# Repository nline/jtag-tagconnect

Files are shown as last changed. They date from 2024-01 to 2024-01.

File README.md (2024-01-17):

JTAG to Tag Connect
===================

This PCB is an adapter that converts the [20 pin JLink](https://www.segger.com/jlink-debug-probes.html) connector to
a [6-pin Tag Connect](http://www.tag-connect.com/TC2030-IDC-NL),
much like [this](https://www.segger.com/jlink-6-pin-adapter.html) board.
Ours, however, additionally contains an onboard LDO
that can supply 3.3V to the attached device and the VTRef pin on the J-Link programmer
so that it can program boards that are not self powered.

This most recent (nLine) version allows you to additionally power the target board with 5V and
also select the whether to keep the I/O at the supply voltage or divide it down from 5V to 3V3. 
This allows powering higher voltage boards while still operating the MCU at 3V3 without on-board
level shifters.

Interface
---------

- **Switch 1**, labeled `VSupply`: Set to 5V to connect teh VCC pin on the TagConnect
header (and the attached board) to the 5VC output from the JLink.
Set to `3V3` to connect the `VCC` pin on the TagConnect
header (and the attached board to be programmed) and the `VTRef` pin from
the Segger JLink to the 3.3 V output from the regulator.
Set to `DEV` to directly connect the `VTRef` pin on the JLink to the TagConnect
VCC pin. This sets the I/O voltage for the JLink, but does not power the target board.

- **Switch 2**, labeled `SWDIO`: This switch can connect the `SWDIO` and
`!RESET` signals, which is needed on some ICs. To leave the signals
disconnected, leave the switch in the empty (down) position.

- **Switch 3** labeled `VIO`: Set to `Supply` to use with I/O voltage same as VSupply. Set to
`5V->3V3` to divide a 5V supply down to 3V3 for 3V3 I/O operation.

Troubleshooting
---------------

1. Blue LED does not come on when attached to JLink.
You need to enable the 5 V output on the JLink:

        $ JlinkExe
        power on perm

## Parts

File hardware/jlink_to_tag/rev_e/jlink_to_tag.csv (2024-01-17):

Qty | Value | Device | Package | Parts | Description | DIGIKEY | MF | MPN | OC_FARNELL | OC_NEWARK | PROD_ID | VALUE
1 |  | ML20 | ML20 | J1 | HARTING | S9172-ND |  |  | unknown | unknown
2 | 0.01uF | C-EUC0603 | C0603 | C1, C2 | CAPACITOR, European symbol | 490-1512-1-ND
1 | 10k | RESISTOR0603_RES | 0603-RES | R2 | Resistor | RMCF0603FT10K0CT-ND
1 | 10uF | CAP_POL1206 | EIA3216 | C3 | Capacitor Polarized | 399-3684-1-ND
1 | 20k | RESISTOR0603_RES | 0603-RES | R3 | Resistor | P20.0KHCT-ND
1 | 470 | RESISTOR0603-RES | 0603-RES | R1 | Resistor | P470DBCT-ND
1 | BLUE | LED-BLUE0603 | LED-0603 | D1 | Blue LEDs for production use | 160-1827-1-ND |  |  |  |  | DIO-08575 | BLUE
1 | EVQP2 | EVQP2 | EVQP2 | S1 | SWITCH TACTILE SPST-NO 0.02A 15V | P11084SCT-ND
1 | JLINK_6PIN_TAG-CON | JLINK_6PIN_TAG-CON | 2X3_MALE_SHROUDED_0.100 | J2 | This is a 6-pin Tag Connect header with the J-Link. | 3M15451-ND
1 | LT1763CS8-3.3 | LT1763CS8-3.3 | SOIC8 | U1 | 500mA, Low Noise, LDO Micropower Regulators | LT1763CS8-3.3#TRPBFCT-ND |  | LT1763CS8-3.3 | 1273617 | 57M6055
1 | OS103011MS8QP1 | OS103011MS8QP1 | OS102011MS8QP1 | S4 | Slide Switch SP3T Through Hole | CKN9543-ND
2 | TE_SSA12/SPDT | TE_SSA12/SPDT | TE_SSA12/SPDT | S2, S3 | SWITCH SLIDE SPDT 2POS SSA SER | 2223-SLW-883935-2A-D-ND |  | SLW-883935-2A-D

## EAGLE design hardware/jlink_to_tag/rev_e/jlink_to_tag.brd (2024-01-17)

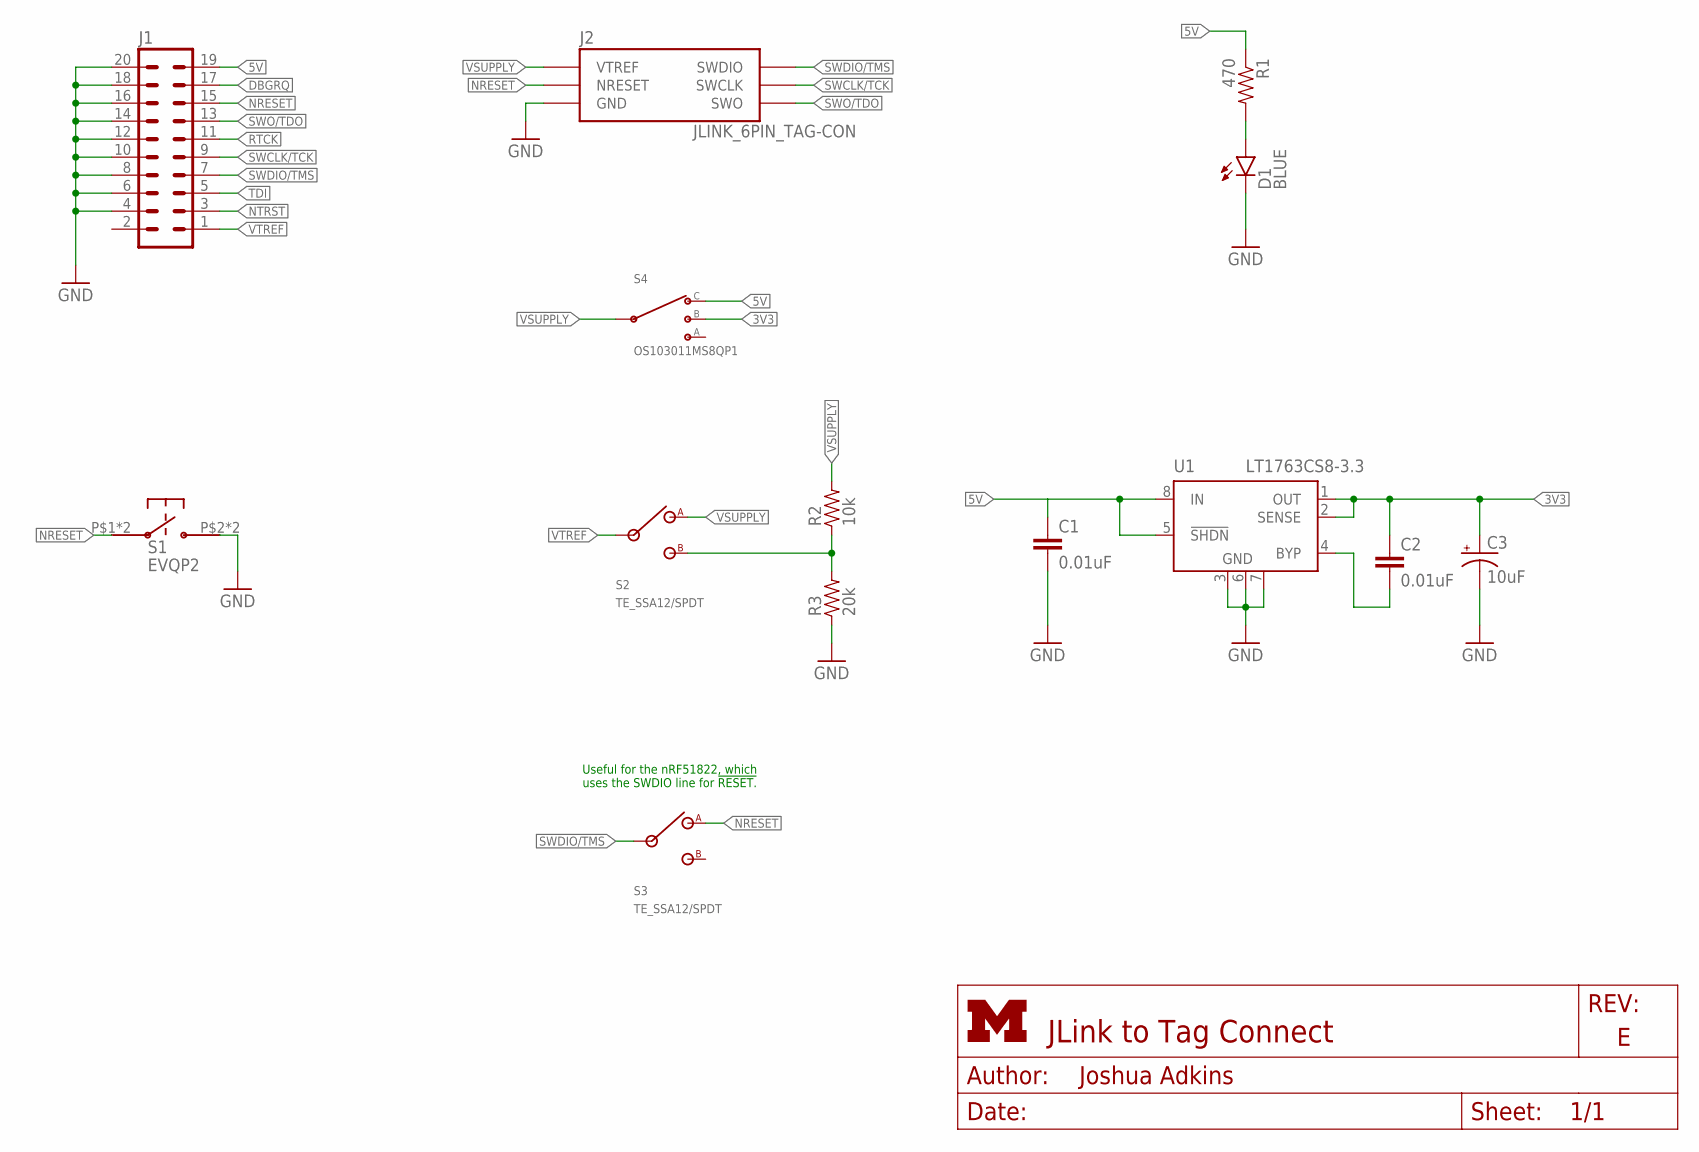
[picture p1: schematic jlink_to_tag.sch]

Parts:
C1, C2: 0.01uF; C0603; DIGIKEY 490-1512-1-ND
C3: 10uF; EIA3216; DIGIKEY 399-3684-1-ND
D1: BLUE; LED-0603; DIGIKEY 160-1827-1-ND
J1: ML20; DIGIKEY S9172-ND
J2: JLINK_6PIN_TAG-CON; 2X3_MALE_SHROUDED_0.100
R1: 470; 0603-RES; DIGIKEY P470DBCT-ND
R2: 10k; 0603-RES; DIGIKEY RMCF0603FT10K0CT-ND
R3: 20k; 0603-RES; DIGIKEY P20.0KHCT-ND
S1: EVQP2
S2, S3: TE_SSA12/SPDT; MPN SLW-883935-2A-D; DIGIKEY 2223-SLW-883935-2A-D-ND
S4: OS103011MS8QP1; OS102011MS8QP1
U1: LT1763CS8-3.3; SOIC8; DIGIKEY LT1763CS8-3.3#TRPBFCT-ND

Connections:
3V3: C2.1, C3.A (+), S4.3 (2), U1.1 (OUT), U1.2 (SENSE)
5V: C1.1, J1.19, R1.1, S4.4 (3), U1.5 (!SHDN), U1.8 (IN)
DBGRQ: J1.17
GND: C1.2, C3.C (-), D1.C, J1.4, J1.6, J1.8, J1.10, J1.12, J1.14, J1.16, J1.18, J1.20, J2.5 (GND), R3.1, S1.P$2, S1.P$4, U1.3 (GND), U1.6 (GND), U1.7 (GND)
unnamed: R2.1, R3.2, S2.2 (B)
unnamed: D1.A, R1.2
unnamed: C2.2, U1.4 (BYP)
NRESET: J1.15, J2.3 (NRESET), S1.P$1, S1.P$3, S3.1 (A)
NTRST: J1.3
RTCK: J1.11
SWCLK/TCK: J1.9, J2.4 (SWCLK)
SWDIO/TMS: J1.7, J2.2 (SWDIO), S3.IN
SWO/TDO: J1.13, J2.6 (SWO)
TDI: J1.5
VSUPPLY: J2.1 (VTREF), R2.2, S2.1 (A), S4.2 (C)
VTREF: J1.1, S2.IN

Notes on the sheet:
Useful for the nRF51822, which uses the SWDIO line for !RESET.

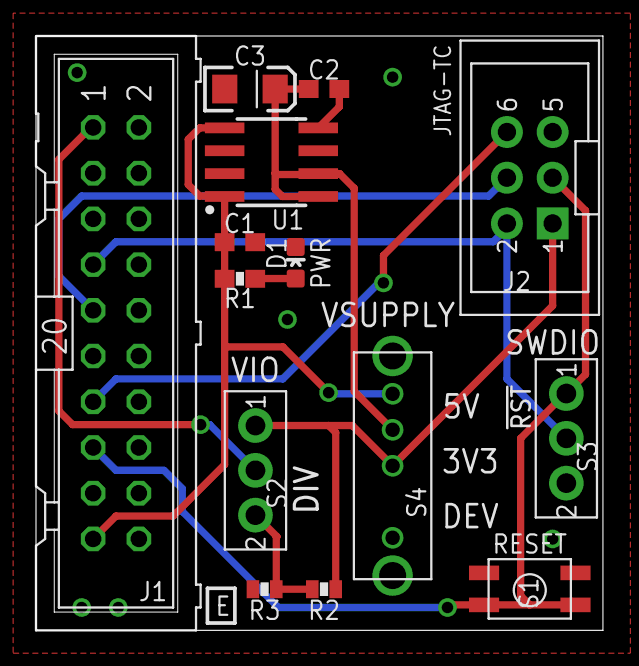
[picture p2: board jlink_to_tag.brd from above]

Board: 2 copper layers, 31.5 x 33.0 mm, 14 parts (0 on the bottom side), 12 nets.

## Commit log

2024-01-17 add 3rd switch for 5V supply but 3V3 IO
    [jlink_to_tag.brd, jlink_to_tag.sch]
2024-01-17 update part numbers
    [jlink_to_tag.brd, jlink_to_tag.sch]
2024-01-17 add BOM and final changes
    [jlink_to_tag.brd, jlink_to_tag.csv, jlink_to_tag.sch]

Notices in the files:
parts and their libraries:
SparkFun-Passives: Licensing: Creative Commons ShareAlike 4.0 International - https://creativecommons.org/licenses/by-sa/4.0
